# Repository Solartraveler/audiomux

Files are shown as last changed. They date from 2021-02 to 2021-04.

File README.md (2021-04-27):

# Audiomux
This project provides a box for switching 4 stereo audio inputs to 4 outputs. Any combination of inputs to outputs can be selected at the same time.
Signal dissortion is minimized by using reed relays.
Moreover, this provides galvanic isolation from the control circuit and if the input source can drive a headphone, it will work on the output of the mux too.
Allowing control by two USB ports, this can be easily used for a homeoffice + private PC setup. Controlling with an infrared remote control is possible too.
The power supply can come from one of the USB ports or one of two external 6-12V power supplies.
For each power supply source, one predefined input to output mux configuration can be saved in the internal flash.

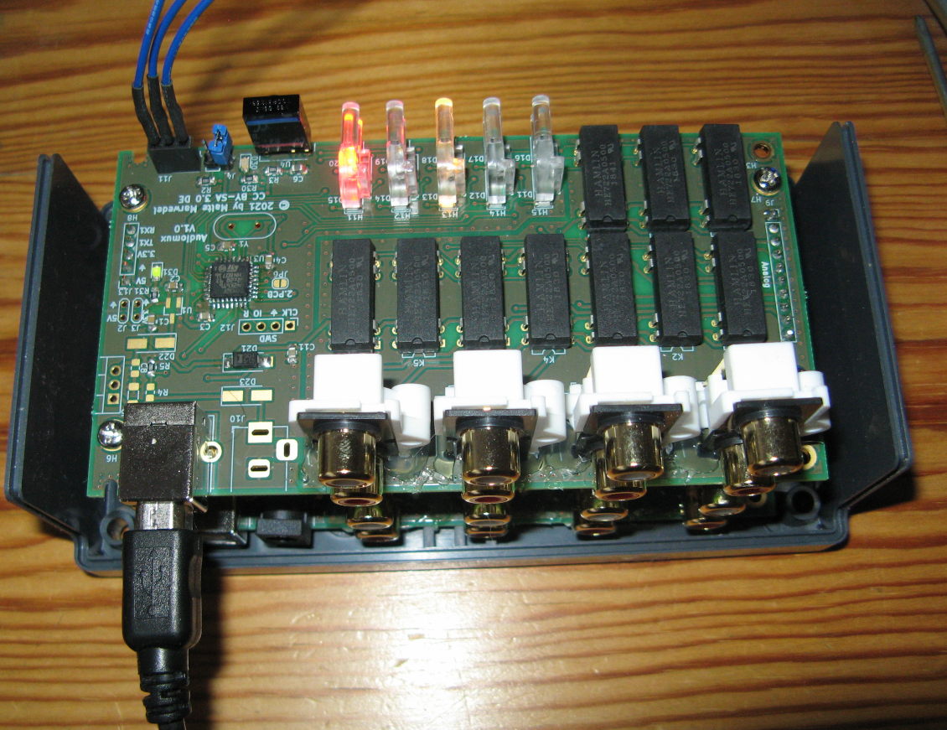
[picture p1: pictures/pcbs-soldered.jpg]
Two PCBs stacked and fully soldered


## Host program
A host program for communicating is provided.
Written in python, it is platform independent. Linux was tested.
Setting output 1 to input 2, call the program as following:

./audiomux-control.py 1 2

Call without parameters to get the current setup. Call

./audiomux-control.py state

to get all predefined configurations for IR remote control codes and Vcc inputs.
The input voltages and internal temperature are printed too.

A debian package can be generated.

## Compiling and uploading

There is no additional programming hardware needed.

With apt install the packages gcc-arm-none-eabi, make, dfu-util and python3-usb.

Next, call make

Then close J4 and call ./dfu-upload.sh

Later, leave J4 open to directly start the flashed program. You have to repeat this for both PCBs.

## Debugging

You can add a serial port with 3.3V level to J11 and see some debug messages when using 19200baud.

Debugging with SWD should be possible too, but this was not tested.

## Bugs

Maybe the biggest bug in the is the counterintuitive ordering of the in and outputs...

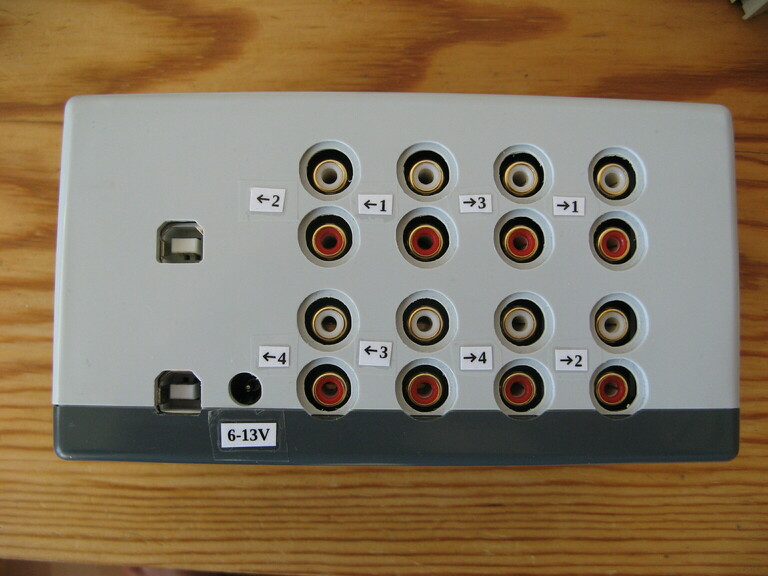
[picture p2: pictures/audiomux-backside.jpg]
Audiomux backside


The soldering bridges would allow switching input (3 and 4) and/or (1 and 2).

## Libraries used and licenses

The software uses several open source libraries with different licenses.

The HAL library from ST is published under the BSD 3-Clause license.

Some CMSIS header files are published under the Apache 2.0 license.

The [IRMP](https://www.mikrocontroller.net/articles/IRMP_-_english) project is published under GPL 2.0 or later.

[Libusb_stm32](https://github.com/dmitrystu/libusb_stm32) is published under the Apache 2.0 license.

Since GPL 2.0 and Apache 2.0 are considered [incompatible](https://www.apache.org/licenses/GPL-compatibility.html) by the Free Software Foundation, but GPL 3.0 is considered compatible, GPL 3.0 is the only possible license for the firmware on the microcontroller side.

The PCB is under creative common license. [CC-BY-SA 3.0 DE](https://creativecommons.org/licenses/by-sa/3.0/de/deed.en)

## Windows users

The device declares itself als WCID compatible and uses WinUSB.
So no driver installation is required.
You still need libusb-1.0.dll either in your system directory or in the same directory as the audiomux-control.py script.
The lib can be found [here](https://libusb.info). Tested with version 1.0.24, the dll can be found in VS2019\MS64\dll.

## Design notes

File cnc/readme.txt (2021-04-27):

All FreeCAD files are created with version 0.18
All milling was done with 2mm diameter.

AudiomuxVer9-0 -> Backside milling for the connectors
exported nc file: backVer9-0.nc
exported frame: export-v9.pdf -> use to place the case and axis x:y zero at the right position. The center of the lower jack cutout is position 0:0.

AudiomuxFrontVer2-0 -> Front milling while using each LED.
Dont use. 1. The upper row of LEDs is 1.6mm too low (forgot the thickness of the PCB).
2. Starting milling in the edge of the holes ends in non round holes - it looks bad.
But this file is the only one which does the IR receiver cutout (at the righ position).

AudiomuxFrontVer5-0 -> Front milling of two windows for the two LED rows.
The larger height of the upper cutout is the result of fixing a previous made error. Reduce the height if you want. The center of origin is one of the LEDs.
exported nc file: ledFrontVer5-0.nc
export-FrontVer4-0.pdf is the outline on the case in the end (with the round corner from AudiomuxFrontVer2).
export-frontVer2-0.pdf can be used to place the milling at the right X-Y 0:0 position.

AudiomuxTransparent2Ver2-0 -> transparent window for the LED cutouts on the front (1x small, 1x large). You should use transparent plastic with 3.5 - 4mm thickness.
exported nc file: AudiomuxTransparent2Ver2-0.nc

AudiomuxTransparent3Ver2-0 -> transparent window for the IR receiver cutouts on the front
exported nc file: AudiomuxTransparent3Ver2-0.nc

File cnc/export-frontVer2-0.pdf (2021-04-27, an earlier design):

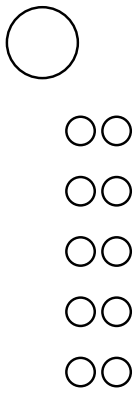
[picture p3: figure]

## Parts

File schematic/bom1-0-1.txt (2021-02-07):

To get the right enumeration of inputs and outputs, place the 1.PCB on top of the 2.PCB.
Then the enumeration of the backside will look linke the following:
Output1 Output2 Input1 Input2 <- 1.PCB
Output3 Output4 Input3 Input4 <- 2.PCB
I reccommend solder the 2.PCB first - then adjusting the height of J9 and J13 headers is easier when the spacers are in place.
U1 may only be present on one PCB. It does not matter which one - but I suggest the one you solder first.

1. and 2. PCB - duplicate number of parts to order
                     Description              Ordner number of reichelt.de
C1, C2               10µF, 16V 0805           X5R-G0805 10/16
C3, C4, C5, C11      100nF 0805               X7R-G0805 100N
D1-D10, D23          Schottky diode SK14      SK 14 DIO
D11-D14, D16-D19     LED yellow PLCC2         LED SMD 2214 GE
D15, D20             LED red    PLCC2         LED SMD 2214 RT
D30                  LED red 0805             OSO LSR976
D31                  LED green 0805           OSO LGR971
H11-H15              dual light pipe          DIAL 515-1094F
J1                   USB B jack               USB BW
J4                   2pin 2.54mm header       MPE 087-1-002
J5-J8                Stereo cinch connector   CBP 2
J11                  3pin socket 2.54mm Debug MPE 094-1-003
K1-K10               Reed relai 2x on         LITT HE722A0500
Q1-Q10               BSS138 N channel mosfet  BSS 138 SMD
R1, R5, R7           10k 0805                 SMD-0805 10,0K
R2, R6               100k 0805                SMD-0805 100K
R11-R20              330 0805                 SMD-0805 330
R21-R24              10 1W 2512               RND 1552512 AA
R30, R31             1k 0805                  SMD-0805 1,00K
U2                   USB esd protection       USBLC6-2SC6
U3                   STM32F042K6T             ---

1.PCB (top):
Jumper for J4        Share with 2. PCB
J9                   10pin long header 2.54mm MPE 089-1-010
J13                  5pin long header 2.54mm  MPE 089-1-005

2.PCB (bottom):
U1                   3.3V regulator, MCP1754S CP 1754-3302CB
J9                   10pin socket 2.54mm      MPE 094-1-010
J13                  5pin socket 2.54mm       MPE 094-1-005

Between 1.PCB and 2.PCB
-- 4x                Spacer 3mm 30mm height   DA 30MM
-- 4x                Screw 3mm                --
-- 4x                Screw-nut 3mm            --

Optional for DC jack:
C7                   10µF, 25V 1206           X7R-G1206 10/25
C8                   10µF, 16V 0805           X5R-G0805 10/16
D21, D22             Schottky diode SK14      SK 14 DIO
J10                  DC Jack                  DC BU21 90
R4                   100k 0805                SMD-0805 100K
U5                   5V regulator, min 400mA  LM 2937 ET-5.0
Heatsink for U5:     TO220, <=78K/K           ---

Optional for IR receiver.
Suggestion: Solder only on 2.PCB - its higer and therefore the view
is less likely blocked by other things on a table or elsewhere.
R3                   100 0805                 SMD-0805 100
U4                   IR receiver TSOP31236    TSOP 31236
C6                   4.7µF 0805               KEM X5R0805 4,7U

Optional for crystal:
C9, C10              22pF 0805                NPO-G0805 22P
Y1                   8MHz crystal             8,0000-HC49U-S

Optional for debugging:
J12                  SWD debug 4pin header    MPE 087-1-004

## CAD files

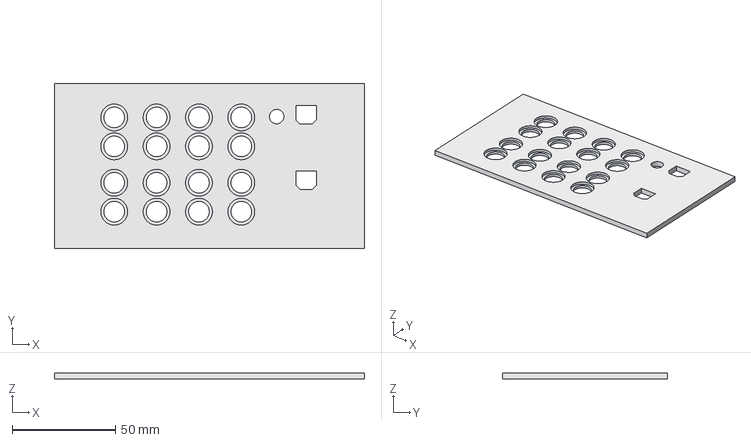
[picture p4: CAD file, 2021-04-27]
cnc/AudiomuxVer9-0.FCStd
150.0 x 80.0 x 3.00 mm

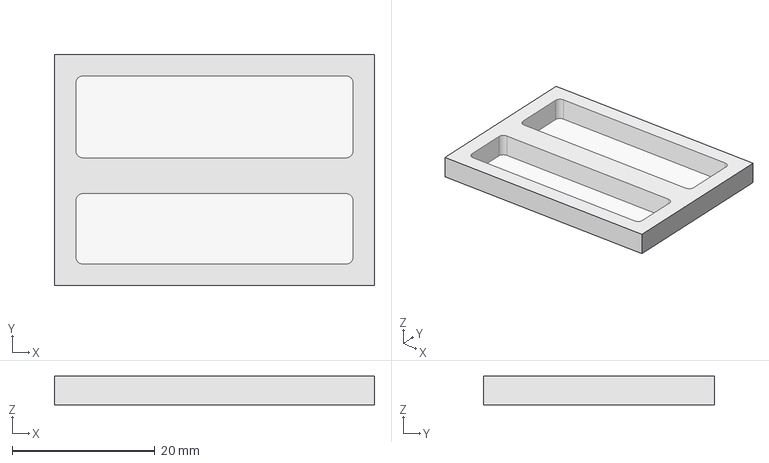
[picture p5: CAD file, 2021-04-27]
cnc/AudiomuxTransparent2Ver2-0.FCStd
44.8 x 32.4 x 4.00 mm
Model-Body
Stock001

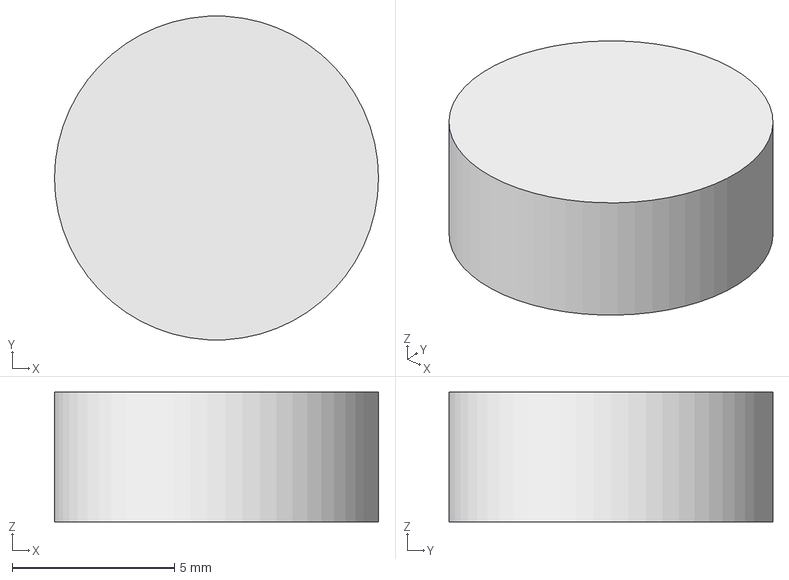
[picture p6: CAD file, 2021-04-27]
cnc/AudiomuxTransparent3Ver2-0.FCStd
10.0 x 9.99 x 4.00 mm

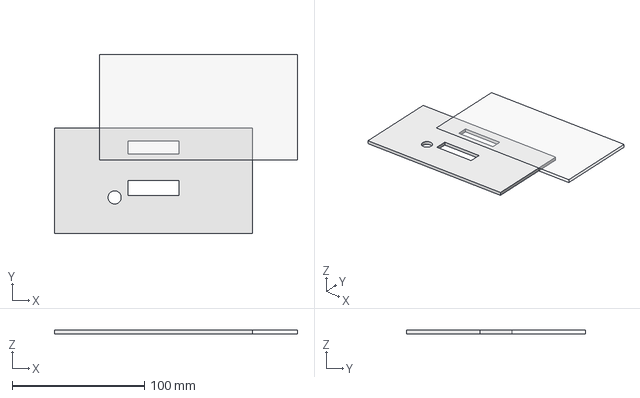
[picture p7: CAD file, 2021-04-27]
cnc/AudiomuxFrontVer5-0.FCStd
184.0 x 135.5 x 3.00 mm
Model-Body
Stock001

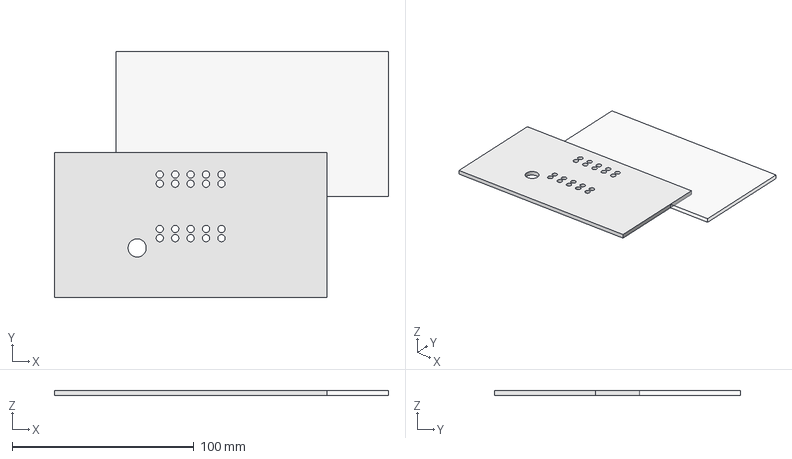
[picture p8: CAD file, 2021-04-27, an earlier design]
cnc/AudiomuxFrontVer2-0.FCStd
184.0 x 135.5 x 3.00 mm
Model-Body
Stock001

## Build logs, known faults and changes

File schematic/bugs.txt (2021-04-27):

For a revision 1.1, I suggest fixing:
1.
The footprint of J5-J8 needs elongated holes approx 0.2mm more wide. Its currently difficult to press the plastic holders of the audio connector into it.
2.
U5 and H6 are very close together - its therefore difficult to find a proper of-the-shelf headsink.
3.
The footprint for the light pipes H11 - H15 from kicad has 0.02mm smaller drills than recommend in the datasheet.
The connector of the light pipe fits easily in the front hole, but pressing it in the rear hole is difficult.
Maybe 0.1mm more drilling for the rear hole would be right. Or just use a rasp carefully on the light pipes.
4.
The RX and TX pins are directly connected, if the software is not configured properly, or closing one of the 2.PCB JP6 has been forgotten, two outputs would drive against each other. Resistors in the lines of RX1 and RX2 would be safe here.
5.
While in DFU upload mode, the MCU pulls PA9, PA10 and PA15 high, as a result the relays switch and Inputs 3 and 4 are connected together with mute.
Workaround: While uploading firmware, unplug audio inputs 3 and 4.
6.
The holes and cutout for the mounting screws are 2.7mm wide. Its hard to get 2.6mm screws. Increasing the hole/cutout to 3.0mm would allow the use of much more common 2.9mm screws
7.
The order of the in- and outputs went counter intuitive. Looking at the backside it is:
Out2 Out1 In3  In1
Out4 Out3 In4  In2

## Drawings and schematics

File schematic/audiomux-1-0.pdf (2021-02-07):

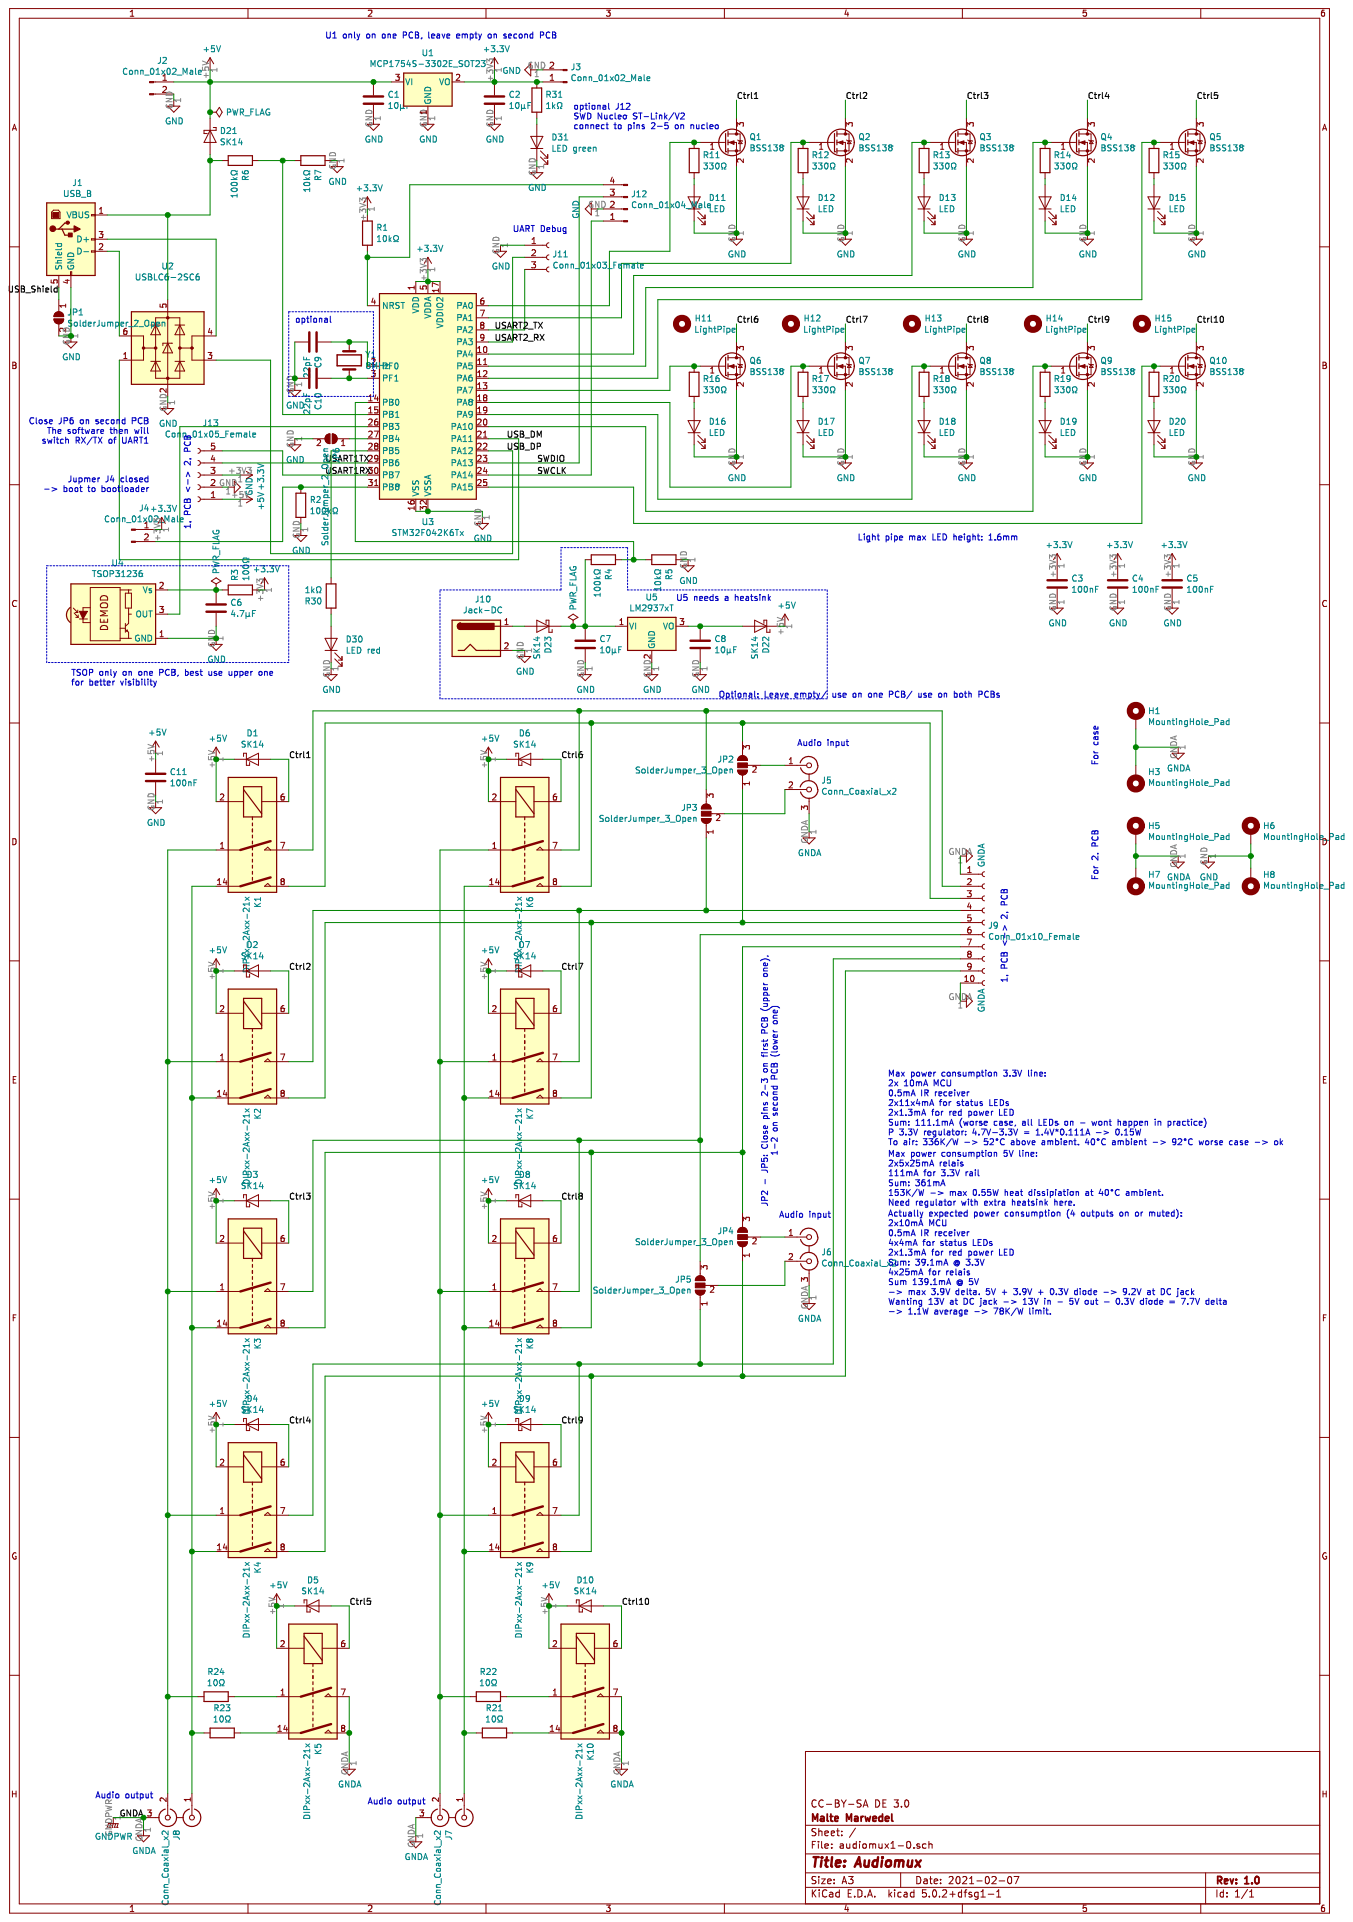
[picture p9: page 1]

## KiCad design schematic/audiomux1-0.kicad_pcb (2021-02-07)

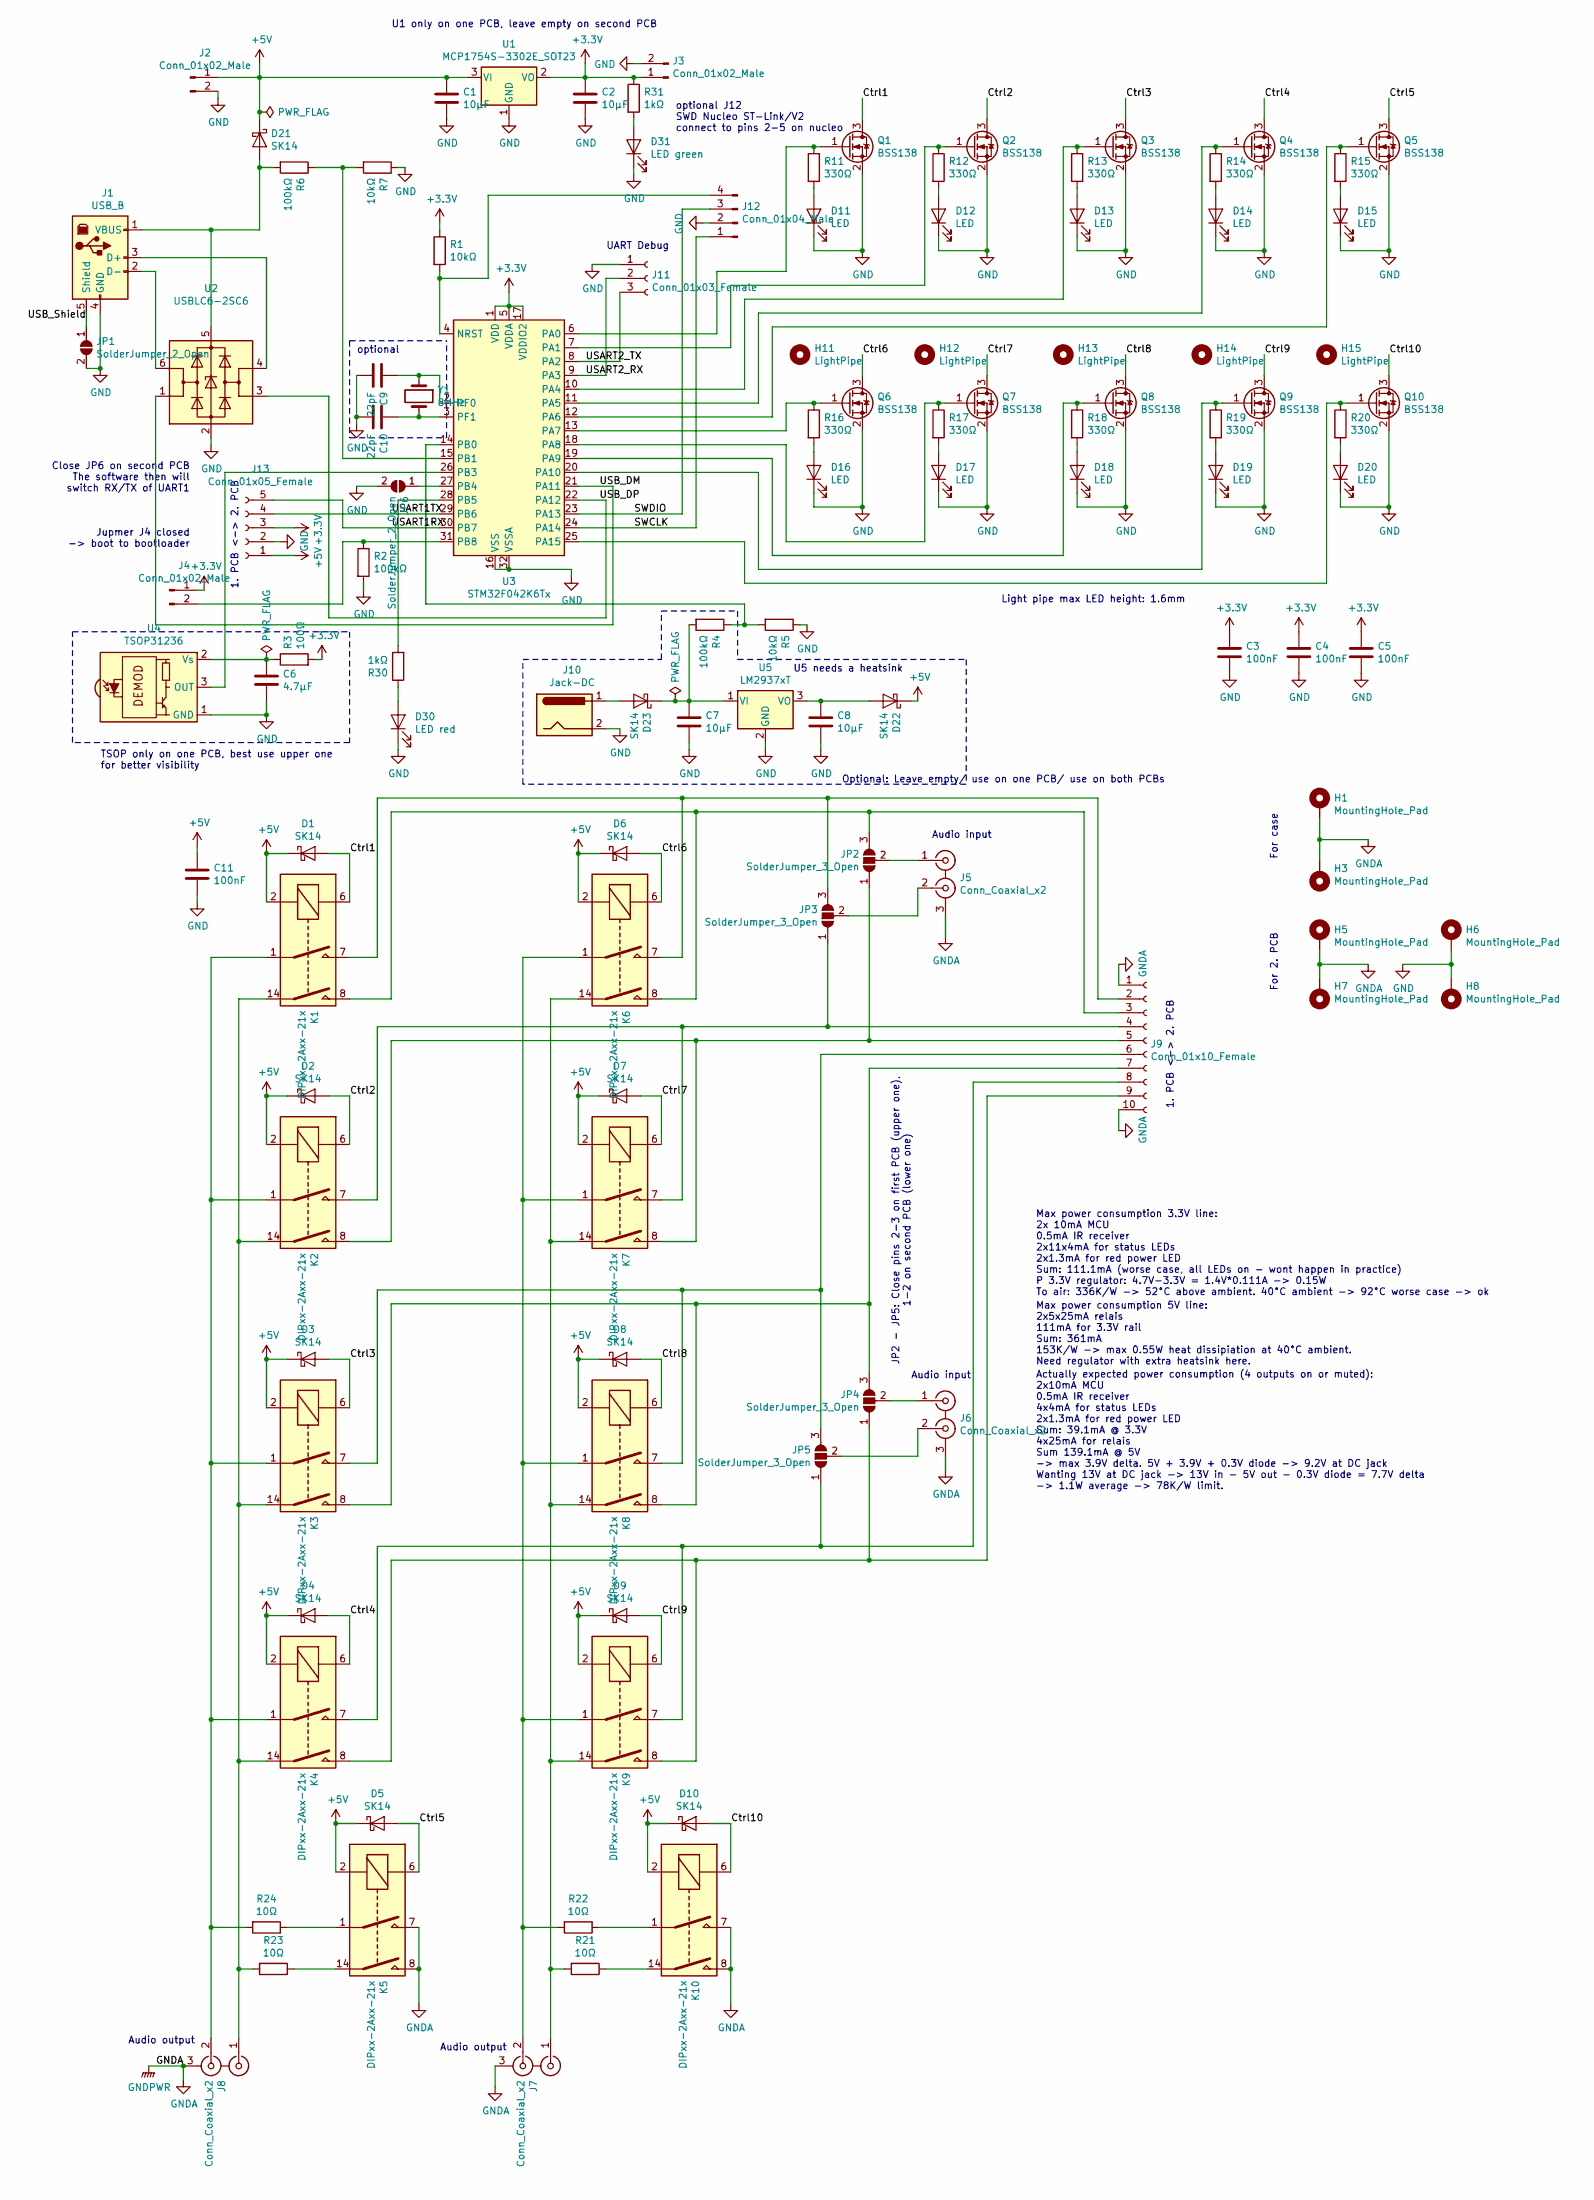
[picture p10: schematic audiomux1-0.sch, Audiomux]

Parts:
C1, C2, C8: 10µF; C_0805_2012Metric_Pad1.18x1.45mm_HandSolder
C3, C4, C5, C11: 100nF; C_0805_2012Metric_Pad1.18x1.45mm_HandSolder
C6: 4.7µF; C_0805_2012Metric_Pad1.18x1.45mm_HandSolder
C7: 10µF; C_1206_3216Metric_Pad1.33x1.80mm_HandSolder
C9, C10: 22pF; C_0805_2012Metric_Pad1.18x1.45mm_HandSolder
D1, D2, D3, D4, D5, D6, D7, D8, D9, D10, D21, D22, D23: SK14; D_SMA_Handsoldering
D11, D12, D13, D14, D15, D16, D17, D18, D19, D20: LED; LED_miniPLCC_2315_Handsoldering
D30: LED red; LED_0805_2012Metric_Pad1.15x1.40mm_HandSolder
D31: LED green; LED_0805_2012Metric_Pad1.15x1.40mm_HandSolder
H1, H3: MountingHole_Pad; MountingHole_2.7mm_M2.5_DIN965_Pad
H5, H6, H7, H8: MountingHole_Pad; MountingHole_3.2mm_M3_DIN965_Pad
H11, H12, H13, H14, H15: LightPipe; Lightpipe_LPF-C012303S
J1: USB_B; USB_B_OST_USB-B1HSxx_Horizontal
J2, J3: Conn_01x02_Male; TestPoint_2Pads_Pitch2.54mm_Drill0.8mm
J4: Conn_01x02_Male; PinHeader_1x02_P2.54mm_Vertical
J5, J6, J7, J8: Conn_Coaxial_x2; CBP2
J9: Conn_01x10_Female; PinSocket_1x10_P2.54mm_Vertical
J10: Jack-DC; BarrelJack_Horizontal_HEBW21
J11: Conn_01x03_Female; PinSocket_1x03_P2.54mm_Vertical
J12: Conn_01x04_Male; PinHeader_1x04_P2.54mm_Vertical
J13: Conn_01x05_Female; PinSocket_1x05_P2.54mm_Vertical
JP1, JP6: SolderJumper_2_Open; SolderJumper-2_P1.3mm_Open_RoundedPad1.0x1.5mm
JP2, JP3, JP4, JP5: SolderJumper_3_Open; SolderJumper-3_P1.3mm_Open_RoundedPad1.0x1.5mm
K1, K2, K3, K4, K5, K6, K7, K8, K9, K10: DIPxx-2Axx-21x; Relay_StandexMeder_DIP_LowProfile
Q1, Q2, Q3, Q4, Q5, Q6, Q7, Q8, Q9, Q10: BSS138; SOT-23_Handsoldering
R1, R5, R7: 10kΩ; R_0805_2012Metric_Pad1.20x1.40mm_HandSolder
R2, R4, R6: 100kΩ; R_0805_2012Metric_Pad1.20x1.40mm_HandSolder
R3: 100Ω; R_0805_2012Metric_Pad1.20x1.40mm_HandSolder
R11, R12, R13, R14, R15, R16, R17, R18, R19, R20: 330Ω; R_0805_2012Metric_Pad1.20x1.40mm_HandSolder
R21, R22, R23, R24: 10Ω; R_2512_6332Metric_Pad1.40x3.35mm_HandSolder
R30, R31: 1kΩ; R_0805_2012Metric_Pad1.20x1.40mm_HandSolder
U1: MCP1754S-3302E_SOT23; SOT-23_Handsoldering
U2: USBLC6-2SC6; SOT-23-6
U3: STM32F042K6Tx; LQFP-32_7x7mm_P0.8mm
U4: TSOP31236; Vishay_CAST-3Pin
U5: LM2937xT; TO-220-3_Vertical
Y1: 8MHz; Crystal_HC49-U_Vertical

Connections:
+3V3: C2.1, C3.1, C4.1, C5.1, J3.1, J4.1, J13.3, R1.1, R3.2, R31.1, U1.2 (VO), U3.1 (VDD), U3.5 (VDDA), U3.17 (VDDIO2)
+5V: C1.1, C11.1, D1.1 (K), D2.1 (K), D3.1 (K), D4.1 (K), D5.1 (K), D6.1 (K), D7.1 (K), D8.1 (K), D9.1 (K), D10.1 (K), D21.1 (K), D22.1 (K), J2.1, J13.1, K1.2, K2.2, K3.2, K4.2, K5.2, K6.2, K7.2, K8.2, K9.2, K10.2, U1.3 (VI)
/Ctrl1: D1.2 (A), K1.6, Q1.3 (D)
/Ctrl2: D2.2 (A), K2.6, Q2.3 (D)
/Ctrl3: D3.2 (A), K3.6, Q3.3 (D)
/Ctrl4: D4.2 (A), K4.6, Q4.3 (D)
/Ctrl5: D5.2 (A), K5.6, Q5.3 (D)
/Ctrl6: D6.2 (A), K6.6, Q6.3 (D)
/Ctrl7: D7.2 (A), K7.6, Q7.3 (D)
/Ctrl8: D8.2 (A), K8.6, Q8.3 (D)
/Ctrl9: D9.2 (A), K9.6, Q9.3 (D)
/Ctrl10: D10.2 (A), K10.6, Q10.3 (D)
/SWCLK: J12.1, U3.24 (PA14)
/SWDIO: J12.3, U3.23 (PA13)
/USART1RX: J13.5, U3.30 (PB7)
/USART1TX: J13.4, U3.29 (PB6)
/USART2_RX: J11.2, U3.9 (PA3)
/USART2_TX: J11.3, U3.8 (PA2)
/USB_DM: U2.1 (I/O1), U3.21 (PA11)
/USB_DP: U2.3 (I/O2), U3.22 (PA12)
/USB_Shield: J1.5 (Shield), JP1.1 (A)
GND: C1.2, C2.2, C3.2, C4.2, C5.2, C6.2, C7.2, C8.2, C9.2, C10.2, C11.2, D11.1 (K), D12.1 (K), D13.1 (K), D14.1 (K), D15.1 (K), D16.1 (K), D17.1 (K), D18.1 (K), D19.1 (K), D20.1 (K), D30.1 (K), D31.1 (K), H6.1, H8.1, J1.4 (GND), J2.2, J3.2, J10.2, J11.1, J12.2, J13.2, JP1.2 (B), JP6.2 (B), Q1.2 (S), Q2.2 (S), Q3.2 (S), Q4.2 (S), Q5.2 (S), Q6.2 (S), Q7.2 (S), Q8.2 (S), Q9.2 (S), Q10.2 (S), R2.2, R5.1, R7.1, U1.1 (GND), U2.2 (GND), U3.16 (VSS), U3.32 (VSSA), U4.1 (GND), U5.2 (GND)
GNDA: H1.1, H3.1, H5.1, H7.1, J5.3 (EXT), J6.3 (EXT), J7.3 (EXT), J8.3 (EXT), J9.1, J9.10, K5.7, K5.8, K10.7, K10.8
unnamed: C6.1, R3.1, U4.2 (Vs)
unnamed: C7.1, D23.1 (K), R4.2, U5.1 (VI)
unnamed: C8.1, D22.2 (A), U5.3 (VO)
unnamed: C9.1, U3.2 (PF0), Y1.1
unnamed: C10.1, U3.3 (PF1), Y1.2
unnamed: D11.2 (A), R11.2
unnamed: D12.2 (A), R12.2
unnamed: D13.2 (A), R13.2
unnamed: D14.2 (A), R14.2
unnamed: D15.2 (A), R15.2
unnamed: D16.2 (A), R16.2
unnamed: D17.2 (A), R17.2
unnamed: D18.2 (A), R18.2
unnamed: D19.2 (A), R19.2
unnamed: D20.2 (A), R20.2
unnamed: D21.2 (A), J1.1 (VBUS), R6.2, U2.5 (VBUS)
unnamed: D23.2 (A), J10.1
unnamed: D30.2 (A), R30.1
unnamed: D31.2 (A), R31.2
unnamed: J1.2 (D-), U2.6 (I/O1)
unnamed: J1.3 (D+), U2.4 (I/O2)
unnamed: J4.2, R2.1, U3.31 (PB8)
unnamed: J5.1 (IN1), JP2.2 (C)
unnamed: J5.2 (IN2), JP3.2 (C)
unnamed: J6.1 (IN1), JP4.2 (C)
unnamed: J6.2 (IN2), JP5.2 (C)
unnamed: J7.1 (IN1), K6.14, K7.14, K8.14, K9.14, R21.2
unnamed: J7.2 (IN2), K6.1, K7.1, K8.1, K9.1, R22.2
unnamed: J8.1 (IN1), K1.14, K2.14, K3.14, K4.14, R23.2
unnamed: J8.2 (IN2), K1.1, K2.1, K3.1, K4.1, R24.2
unnamed: J9.2, JP3.3 (B), K1.7, K6.7
unnamed: J9.3, JP2.3 (B), K1.8, K6.8
unnamed: J9.4, JP3.1 (A), K2.7, K7.7
unnamed: J9.5, JP2.1 (A), K2.8, K7.8
unnamed: J9.6, JP5.3 (B), K3.7, K8.7
unnamed: J9.7, JP4.3 (B), K3.8, K8.8
unnamed: J9.8, JP5.1 (A), K4.7, K9.7
unnamed: J9.9, JP4.1 (A), K4.8, K9.8
unnamed: J12.4, R1.2, U3.4 (NRST)
unnamed: JP6.1 (A), U3.27 (PB4)
unnamed: K5.1, R24.1
unnamed: K5.14, R23.1
unnamed: K10.1, R22.1
unnamed: K10.14, R21.1
unnamed: Q1.1 (G), R11.1, U3.6 (PA0)
unnamed: Q2.1 (G), R12.1, U3.7 (PA1)
unnamed: Q3.1 (G), R13.1, U3.10 (PA4)
unnamed: Q4.1 (G), R14.1, U3.11 (PA5)
unnamed: Q5.1 (G), R15.1, U3.12 (PA6)
unnamed: Q6.1 (G), R16.1, U3.13 (PA7)
unnamed: Q7.1 (G), R17.1, U3.18 (PA8)
unnamed: Q8.1 (G), R18.1, U3.19 (PA9)
unnamed: Q9.1 (G), R19.1, U3.20 (PA10)
unnamed: Q10.1 (G), R20.1, U3.25 (PA15)
unnamed: R4.1, R5.2, U3.14 (PB0)
unnamed: R6.1, R7.2, U3.15 (PB1)
unnamed: R30.2, U3.28 (PB5)
unnamed: U3.26 (PB3), U4.3 (OUT)

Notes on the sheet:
Jupmer J4 closed -> boot to bootloader
U1 only on one PCB, leave empty on second PCB
optional J12 SWD Nucleo ST-Link/V2 connect to pins 2-5 on nucleo
UART Debug
Max power consumption 3.3V line: 2x 10mA MCU 0.5mA IR receiver 2x11x4mA for status LEDs 2x1.3mA for red power LED Sum: 111.1mA (worse case, all LEDs on - wont happen in practice) P 3.3V regulator: 4.7V-3.3V = 1.4V*0.111A -> 0.15W To air: 336K/W -> 52°C above ambient. 40°C ambient -> 92°C worse case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
Max power consumption 5V line: 2x5x25mA relais 111mA for 3.3V rail Sum: 361mA 153K/W -> max 0.55W heat dissipiation at 40°C ambient. Need regulator with extra heatsink here.
Actually expected power consumption (4 outputs on or muted): 2x10mA MCU 0.5mA IR receiver 4x4mA for status LEDs 2x1.3mA for red power LED Sum: 39.1mA @ 3.3V 4x25mA for relais Sum 139.1mA @ 5V -> max 3.9V delta. 5V + 3.9V + 0.3V diode -> 9.2V at DC jack Wanting 13V at DC jack -> 13V in - 5V out - 0.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
Close JP6 on second PCB The software then will switch RX/TX of UART1
Optional: Leave empty/ use on one PCB/ use on both PCBs
U5 needs a heatsink
JP2 - JP5: Close pins 2-3 on first PCB (upper one), 1-2 on second PCB (lower one)
For case
For 2. PCB
optional
Light pipe max LED height: 1.6mm
Audio input
Audio output
1. PCB <-> 2. PCB
TSOP only on one PCB, best use upper one for better visibility

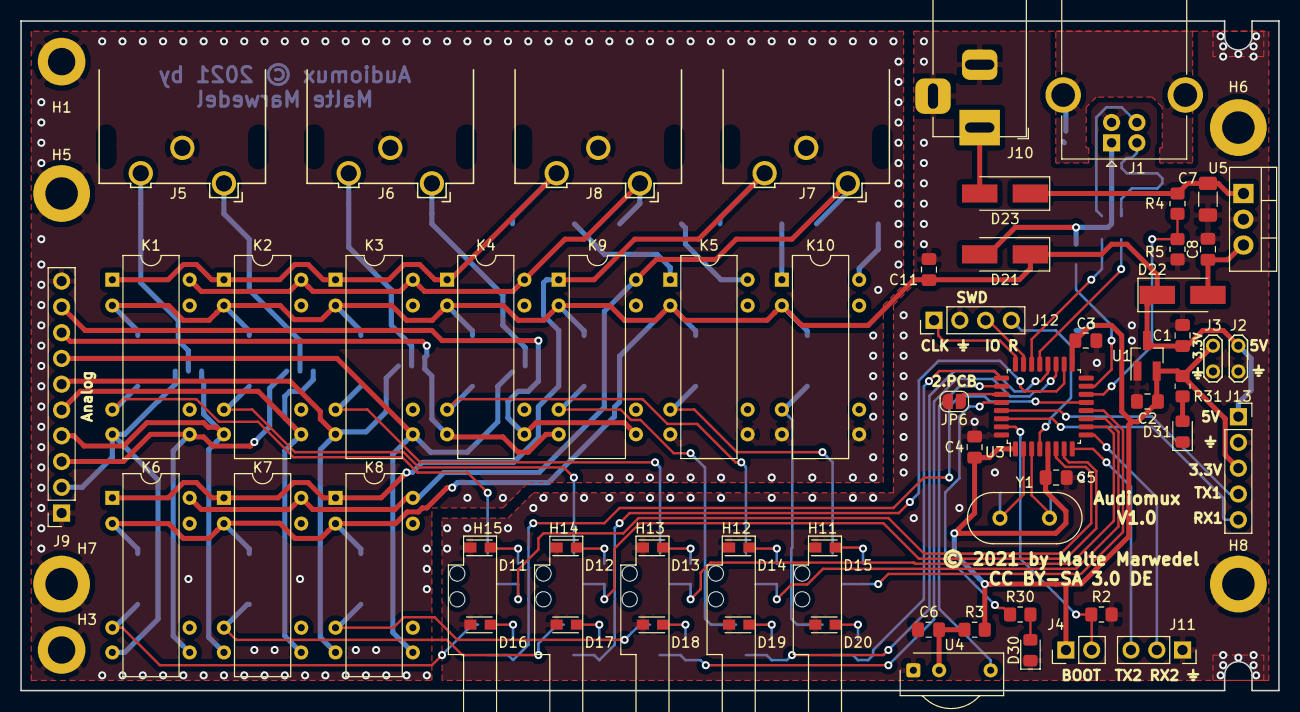
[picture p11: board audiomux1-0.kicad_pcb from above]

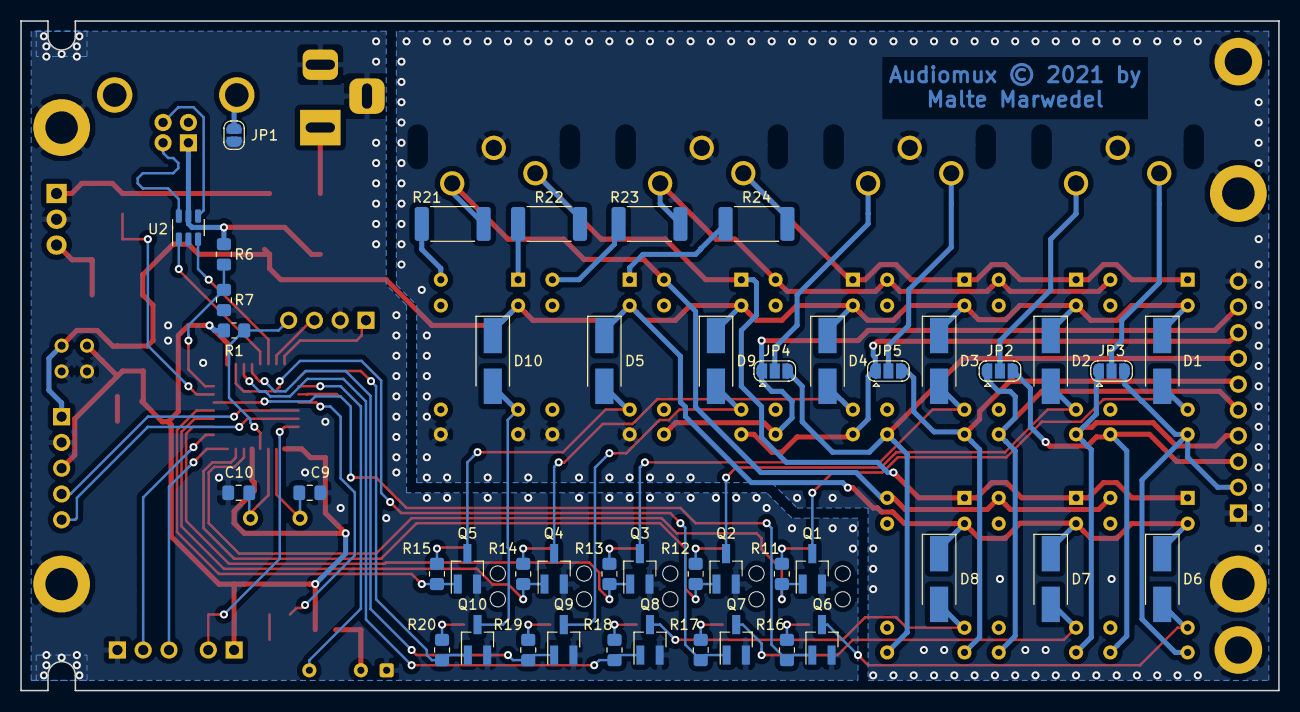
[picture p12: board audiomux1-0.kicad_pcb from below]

Board: 2 copper layers, 124.0 x 66.0 mm, 115 parts (45 on the bottom side), 81 nets.

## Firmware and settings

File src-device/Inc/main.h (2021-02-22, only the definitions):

#define Crystal0_Pin GPIO_PIN_0
#define Crystal0_GPIO_Port GPIOF
#define Crystal1_Pin GPIO_PIN_1
#define Crystal1_GPIO_Port GPIOF
#define SoundA1_Pin GPIO_PIN_0
#define SoundA1_GPIO_Port GPIOA
#define SoundA2_Pin GPIO_PIN_1
#define SoundA2_GPIO_Port GPIOA
#define SoundA3_Pin GPIO_PIN_4
#define SoundA3_GPIO_Port GPIOA
#define SoundA4_Pin GPIO_PIN_5
#define SoundA4_GPIO_Port GPIOA
#define SoundAMute_Pin GPIO_PIN_6
#define SoundAMute_GPIO_Port GPIOA
#define SoundB1_Pin GPIO_PIN_7
#define SoundB1_GPIO_Port GPIOA
#define JackVcc_Pin GPIO_PIN_0
#define JackVcc_GPIO_Port GPIOB
#define UsbVcc_Pin GPIO_PIN_1
#define UsbVcc_GPIO_Port GPIOB
#define SoundB2_Pin GPIO_PIN_8
#define SoundB2_GPIO_Port GPIOA
#define SoundB3_Pin GPIO_PIN_9
#define SoundB3_GPIO_Port GPIOA
#define SoundB4_Pin GPIO_PIN_10
#define SoundB4_GPIO_Port GPIOA
#define SoundBMute_Pin GPIO_PIN_15
#define SoundBMute_GPIO_Port GPIOA
#define IrReceiver_Pin GPIO_PIN_3
#define IrReceiver_GPIO_Port GPIOB
#define SecondPcb_Pin GPIO_PIN_4
#define SecondPcb_GPIO_Port GPIOB
#define LED_Pin GPIO_PIN_5
#define LED_GPIO_Port GPIOB
#define Boot_Pin GPIO_PIN_8
#define Boot_GPIO_Port GPIOB

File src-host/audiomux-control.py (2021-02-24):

#!/usr/bin/python3

#audiomux control

#(c) 2021 by Malte Marwedel

#This program is free software; you can redistribute it and/or modify it under
#the terms of the GNU General Public License as published by the Free Software
#Foundation; either version 2 of the License, or (at your option) any later
#version.
#This program is distributed in the hope that it will be useful, but WITHOUT ANY
# WARRANTY; without even the implied warranty of MERCHANTABILITY or FITNESS FOR
# A PARTICULAR PURPOSE. See the GNU General Public License for more details.

#You should have received a copy of the GNU General Public License along with
# this program; if not, write to the Free Software Foundation, Inc., 51 Franklin
# Street, Fifth Floor, Boston, MA 02110-1301, USA.

#version 0.8.0, tested with python 3.7

#Control codes:
# bmRequest = 0 -> set/get mux, wIndex = 0...3 + 1 data byte
# bmRequest = 1 -> save as default/get default, getter has 4 databytes
#                                   wIndex = 0 -> USB
#                                   wIndex = 1 -> DC jack
# bmRequest = 2 -> save/get ir slot data, getter has 11 databytes
#                                   wIndex = 1...16
# bmRequest = 3 -> delete ir slot data, wIndex = 1...16
# bmRequest = 4 -> device reset, 0 data bytes
# bmRequest = 5 -> get sensors wIndex = 0 -> USB voltage in mV, 2 data bytes
#                              wIndex = 1 -> DC jack voltage voltage in mV, 2 data bytes
#                              wIndex = 2 -> temperature in °C
# bmRequest = 6 -> get PCB id. May be 1 or 2, 1 data byte.
# bmRequest = 7 -> Get if other PCB MCU is sending. 1 Got ping within 3s. 1 data byte

import sys
from os import path
import time

MuxOutputs = 4
MuxInputs = 4
MuxNc = 15
PresetSlots = 16

def printOutputState(spaces, out, inp):
	if (inp == 0):
		print(spaces + 'Output ' + str(out) + ': muted')
	elif (inp == MuxNc):
		print(spaces + 'Output ' + str(out) + ': not connected')
	else:
		print(spaces + 'Output ' + str(out) + ': Input ' + str(inp))


def showCurrentMux(dev):
	print('Current state:')
	for i in range(1, MuxOutputs + 1):
		deviceArray = dev.ctrl_transfer(bmRequestRecv, 0, 0, i, 1)
		printOutputState('  ', i, deviceArray[0])

def showCurrentState(dev):
	showCurrentMux(dev)

	deviceArray = dev.ctrl_transfer(bmRequestRecv, 1, 0, 0, 4)
	print('On USB power:')
	for i in range(0, MuxOutputs):
		printOutputState('  ', i + 1, deviceArray[i])

	deviceArray = dev.ctrl_transfer(bmRequestRecv, 1, 0, 1, 4)
	print('On DC jack power:')
	for i in range(0, MuxOutputs):
		printOutputState('  ', i + 1, deviceArray[i])

	print('IR presets:')
	for i in range(1, PresetSlots + 1):
		deviceArray = dev.ctrl_transfer(bmRequestRecv, 2, 0, i, 7 + MuxOutputs)
		protocol = deviceArray[0]
		address = (deviceArray[2] << 8) | deviceArray[1]
		command = (deviceArray[6] << 24) | (deviceArray[5] << 16) | (deviceArray[4] << 8) | deviceArray[3]
		if protocol or address or command:
			print('  Slot' + str(i) + ':')
			print('    Protocol: ' + str(protocol) + ', address: ' + str(address) + ', command: ' + str(command))
			for j in range(1, MuxOutputs + 1):
				inp = deviceArray[6 + j]
				printOutputState('    ', j, inp)
		else:
			print('  Slot' + str(i) + ': Unused')

	print('Voltages:')
	deviceArray = dev.ctrl_transfer(bmRequestRecv, 5, 0, 0, 2)
	usbvoltage = (deviceArray[1] << 8) | deviceArray[0]
	print('  USB: ' + str(usbvoltage) + 'mV')
	deviceArray = dev.ctrl_transfer(bmRequestRecv, 5, 0, 1, 2)
	vccvoltage = (deviceArray[1] << 8) | deviceArray[0]
	print('  Jack: ' + str(vccvoltage) + 'mV')
	deviceArray = dev.ctrl_transfer(bmRequestRecv, 5, 0, 2, 2)
	temperature = (deviceArray[1] << 8) | deviceArray[0]
	if (temperature >= 0x8000):
		temperature = temperature - 0x10000
	print('Temperature: ' + str(temperature) + '°C')
	deviceArray = dev.ctrl_transfer(bmRequestRecv, 6, 0, 0, 1)
	print('PCB id: ' + str(deviceArray[0]))
	deviceArray = dev.ctrl_transfer(bmRequestRecv, 7, 0, 0, 1)
	if (deviceArray[0]):
		print('Other MCU: running')
	else:
		print('Other MCU: Error, no response')


def saveAsDefaultUsb(dev):
	dev.ctrl_transfer(bmRequestSend, 1, 0, 0, 0)
	return(True)

def saveAsDefaultJack(dev):
	dev.ctrl_transfer(bmRequestSend, 1, 0, 1, 0)
	return(True)

def storeIr(dev, slotStr):
	slot = int(slotStr, 0)
	if not (0 < slot <= PresetSlots):
		print('Error, slot >' + slotStr + '< unsupported')
		return(False)
	dev.ctrl_transfer(bmRequestSend, 2, 0, slot, 0)
	return(True)

def deleteIr(dev, slotStr):
	slot = int(slotStr, 0)
	if not (0 < slot <= PresetSlots):
		print('Error, slot >' + slotStr + '< unsupported')
		return(False)
	dev.ctrl_transfer(bmRequestSend, 3, 0, slot, 0)
	return(True)

def switchMux(dev, outputStr, inputStr):
	out = int(outputStr, 0)
	if inputStr == 'off':
		inx = 0
	elif inputStr == 'nc':
		inx = MuxNc
	else:
		inx = int(inputStr, 0)
	if not (1 <= out <= MuxOutputs):
		print('Error, output out of range')
		return(False)
	if (not (0 <= inx <= MuxInputs)) and (not (inx == MuxNc)):
		print('Error, input out of range')
		return(False)
	usbdata = bytearray(1)
	usbdata[0] = inx
	dev.ctrl_transfer(bmRequestSend, 0, 0, out, usbdata)
	return(True)

def sendReset(dev):
	dev.ctrl_transfer(bmRequestSend, 4, 0, 0, 0)
	return(True)


parameters = len(sys.argv)

if parameters == 2:
	if (sys.argv[1] == '--help') or (sys.argv[1] == '-h'):
		print('audiomux control')
		print('(c) 2021 by Malte Marwedel. Licensed under GPL v2 or later')
		print('')
		print('Usage:')
		print('--help:        Prints this screen')
		print('--version:     Prints the version')
		print('For most setter commands, there is a queue on the other side with up to 8 entries')
		print('<output> <input>: changes the output')
		print('  Numbers can be in decimal or hexadecimal or off or nc (not connected)')
		print('  Example: 2 off')
		print('  Example: 2 1')
		print('  Example: 3 nc')
		print('audiomuxreset: Resets the device. Ignoring the command queue. Both USB ports are being resetted')
		print('savedefaultusb: Save the current state as default if the device is powered over USB')
		print('savedefaultjack: Save the current state as default if the device is powered over an DC jack')
		print('storeir <index>: Save the current state with the next IR remote code to be received. <index> is the slot to use 1...' + str(PresetSlots))
		print('deleteir <index>: Do not use the infrared code anylonger')
		print('state: Print all permanent settings and current state')
		print('Call without parameter: Prints the current state of all mux outputs and internal storage')
		print('')
		print('Return codes:')
		print('0: Command sent')
		print('1: Invalid command')
		print('2: python USB library not installed')
		print('3: No proper backend')
		print('4: USB device not found, or product name wrong')
		sys.exit(0)
	if (sys.argv[1] == '--version'):
		print('Version 0.8.0')
		sys.exit(0)

try:
	import usb.core
	import usb.util
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

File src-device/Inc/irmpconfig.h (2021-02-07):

/*---------------------------------------------------------------------------------------------------------------------------------------------------
 * irmpconfig.h
 *
 * DO NOT INCLUDE THIS FILE, WILL BE INCLUDED BY IRMP.H!
 *
 * Copyright (c) 2009-2020 Frank Meyer - frank(at)fli4l.de
 * Extensions for PIC 12F1820 W.Strobl 2014-07-20
 *
 * This program is free software; you can redistribute it and/or modify
 * it under the terms of the GNU General Public License as published by
 * the Free Software Foundation; either version 2 of the License, or
 * (at your option) any later version.
 *---------------------------------------------------------------------------------------------------------------------------------------------------
 */

#ifndef _IRMP_H_
#  error please include only irmp.h, not irmpconfig.h
#endif

#ifdef IRMPCONFIG_STAGE1_H

/*---------------------------------------------------------------------------------------------------------------------------------------------------
 * Change IRMP_32_BIT here
 *
 * Normally, IRMP_32_BIT ist 0. Then we use irmp.command as a 16 bit value.
 * If you set IRMP_32_BIT to 1, we will use irmp.command as a 32 bit value.
 * A 32 bit command costs more CPU resources on 8 bit processors (e.g. AVR),
 * but there are IR protocols which need more than 16 bits for a reasonable
 * command value.
 *
 * If you want to use one of the following protocols, set IRMP_32_BIT to 1,
 * otherwise set it to 0:
 *    - MERLIN
 *---------------------------------------------------------------------------------------------------------------------------------------------------
 */

#define IRMP_32_BIT                             1                               // use 32 bit command value, 0 or 1

#define ARM_STM32_HAL

#endif // IRMPCONFIG_STAGE1_H

#ifdef IRMPCONFIG_STAGE2_H

/*---------------------------------------------------------------------------------------------------------------------------------------------------
 * Change F_INTERRUPTS if you change the number of interrupts per second,
 * Normally, F_INTERRUPTS should be in the range from 10000 to 15000, typical is 15000
 * A value above 15000 costs additional program space, absolute maximum value is 20000.
 * On PIC with XC8/C18 Compiler, use 15151 as the correct value.
 *---------------------------------------------------------------------------------------------------------------------------------------------------
 */
#ifndef F_INTERRUPTS
#  define F_INTERRUPTS                          10000                           // interrupts per second, min: 10000, max: 20000, typ: 15000
#endif

/*---------------------------------------------------------------------------------------------------------------------------------------------------
 * Change settings from 1 to 0 if you want to disable one or more decoders.
 * This saves program space.
 *
 * 1 enable  decoder
 * 0 disable decoder
 *
 * The standard decoders are enabled per default.
 * Less common protocols are disabled here, you need to enable them manually.
 *
 * If you want to use FDC or RCCAR simultaneous with RC5 protocol, additional program space is required.
 * If you don't need RC5 when using FDC/RCCAR, you should disable RC5.
 * You cannot enable both DENON and RUWIDO, only enable one of them.
 *---------------------------------------------------------------------------------------------------------------------------------------------------
 */

/*---------------------------------------------------------------------------------------------------------------------------------------------------
 * Protocols Part 1: IR decoders
 * If you use a RF receiver, deactivate all IR protocols!
 *---------------------------------------------------------------------------------------------------------------------------------------------------
 */
// typical protocols, disable here!             Enable  Remarks                 F_INTERRUPTS            Program Space
#define IRMP_SUPPORT_SIRCS_PROTOCOL             0       // Sony SIRCS           >= 10000                 ~150 bytes
#define IRMP_SUPPORT_NEC_PROTOCOL               1       // NEC + APPLE + ONKYO  >= 10000                 ~300 bytes
#define IRMP_SUPPORT_SAMSUNG_PROTOCOL           0       // Samsung + Samsg32    >= 10000                 ~300 bytes
#define IRMP_SUPPORT_KASEIKYO_PROTOCOL          0       // Kaseikyo             >= 10000                 ~250 bytes
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

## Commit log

2021-02-07 Inital checkin. Schematic and BOM complete. Host program complete. USB communication works. Each MCU can control the own switches. Inter MCU communication not implemented. IR remote control untestd.
    [audiomux1-0.kicad_pcb, audiomux1-0.sch]
2021-02-12 Add inter MCU communication, fix IR receive. Use HSI with PLL for clock, to make sure the inter MCU communication works reliable. Decrease clock from 12 ot 10MHz - minimum for USB. All planned featur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
    [audiomux.c]
2021-02-14 Increase inter MCU UART frequency Cleanup code - remove parts of the HAL and replace snprintf with own implementation - much smaller.
    [audiomux-control.py, audiomux.c, main.h]
2021-02-20 Change PID. Add code for generating a debian package.
2021-02-21 Optimize library search path for windows and error messages.
    [audiomux-control.py, audiomux.c]
2021-02-22 Replace HAL timer by own implementation. Saves some bytes.
    [audiomux.c, main.h]
2021-04-27 Add CNC files. Show backside of the case
    [AudiomuxFrontVer2-0.FCStd, AudiomuxFrontVer5-0.FCStd, AudiomuxTransparent2Ver2-0.FCStd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]

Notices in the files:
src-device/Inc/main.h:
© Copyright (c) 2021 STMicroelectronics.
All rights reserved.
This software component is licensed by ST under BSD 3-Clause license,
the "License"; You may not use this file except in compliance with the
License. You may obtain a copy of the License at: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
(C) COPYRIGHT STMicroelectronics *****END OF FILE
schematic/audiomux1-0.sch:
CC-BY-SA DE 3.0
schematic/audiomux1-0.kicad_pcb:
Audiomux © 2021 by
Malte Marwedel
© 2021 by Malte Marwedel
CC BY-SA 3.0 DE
